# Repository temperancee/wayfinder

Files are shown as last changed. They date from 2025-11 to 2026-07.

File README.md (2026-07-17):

# Wayfinder

Wayfinder is a custom PCB I designed, containing an ICM-42670-P inertia measurement unit (IMU), a XIAO ESP32S3 Sense, and a barometer. The software is written in C using Arudino libraries and the Espressif-IDF version of FreeRTOS. The ESP32 communicates via I2C with the IMU via a custom driver I wrote. The accelerometer and gyroscope readings are then passed to a Kalman filter, which fuses the sensor data into roll and pitch angles, so you know the orientation of the board!

## Details

The Kalman filter is split into a predict task and a measurement task. The predict task reads gyroscope data, and incorporates it into the angle values using Euler integration. The measurement task reads accelerometer data, maps it to angles, and then incorporates it in the measurement step of the Kalman filter

The predict task runs every two milliseconds, and the measurement task runs every ten. There isn't really any reason for this in this project, although, for higher-end IMUs, accelerometer data is often generated slower than gyroscope data, so such a timing setup would be sensible.

Despite being called `icm_42670_p.cpp`, the code is all C. Arduino requires that external (non `.ino`) files are `.cpp`, rather than `.c`.

The IMU driver is exceedingly simple, and makes no use of the IMU's FIFO buffer. It simply provides commands for reading from the registers that store the gyroscope and accelerometer readings.

<!-- Originally intended to be a quadcopter flight computer, Wayfinder settled for the modest life of being an IMU board. Built using a custom PCB with a XIAO ESP32S3 Sense daughter board, and an ICM-42670-P IMU, this board outputs -->

## Running

If you want to use the driver, simply copy `icm_42670_p.h` and `icm_42670_p.cpp` into your Arduino project. 

## Licesnse

No licesnse. Do as you will with the code.

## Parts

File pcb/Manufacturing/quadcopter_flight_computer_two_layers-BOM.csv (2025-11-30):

Reference | Value | Footprint | Qty | Description | Distributor Link | Manufacturer | Manufacturer Part No. | Type
C1,C2 | 100n | Capacitor_SMD:C_0603_1608Metric | 2 | Unpolarized capacitor, small symbol | https://www.digikey.co.uk/en/products/detail/samsung-electro-mechanics/CL10B104KA8NNNC/3886664 | Samsung Electro-Mechanics | CL10B104KA8NNNC | SMD
C3 | 10n | Capacitor_SMD:C_0402_1005Metric | 1 | Unpolarized capacitor, small symbol | https://www.digikey.co.uk/en/products/detail/samsung-electro-mechanics/CL05B103KB5NNNC/3886686 | Samsung Electro-Mechanics | CL05B103KB5NNNC | SMD
C4 | 100n | Capacitor_SMD:C_0402_1005Metric | 1 | Unpolarized capacitor, small symbol | https://www.digikey.co.uk/en/products/detail/samsung-electro-mechanics/CL05B104KP5NNNC/3886660 | Samsung Electro-Mechanics | CL05B104KP5NNNC | SMD
C5 | 2u2 | Capacitor_SMD:C_0603_1608Metric | 1 | Unpolarized capacitor, small symbol | https://www.digikey.co.uk/en/products/detail/samsung-electro-mechanics/CL10B225KP8NNNC/3886792 | Samsung Electro-Mechanics | CL10B225KP8NNNC | SMD
D1,D2,D3,D4 | D_Small | My_Diode_SMD:D_SOD-123 | 4 | Diode, small symbol | https://www.digikey.co.uk/en/products/detail/diodes-incorporated/1N4148W-7-F/814371 | Diodes Incorporated | 1N4148W-7-F | SMD
D5 | D_TVS | My_Diode_SMD:D_SMA | 1 | Bidirectional transient-voltage-suppression diode, small symbol | https://www.digikey.co.uk/en/products/detail/bourns-inc/SMAJ5-0CA/2254237 | Bourns Inc. | SMAJ5.0CA | SMD
J2 | TO_XIAO | Connector_JST:JST_PH_B2B-PH-K_1x02_P2.00mm_Vertical | 1 | Generic connector, single row, 01x02, script generated (kicad-library-utils/schlib/autogen/connector/) | https://www.digikey.co.uk/en/products/detail/jst-sales-america-inc/B2B-PH-K-S/926611 | JST Sales America Inc. | B2B-PH-K-S | PTH
Q1,Q2,Q3,Q4 | NMOS | MOSFET:DMN1019USN | 4 | N-MOSFET transistor, drain/source/gate | https://www.digikey.co.uk/en/products/detail/diodes-incorporated/DMN1019USN-13/4898821 | Diodes Incorporated | DMN1019USN-13 | SMD
R1,R2,R3,R4 | 10k | Resistor_SMD:R_0603_1608Metric | 4 | Resistor, small symbol | https://www.digikey.co.uk/en/products/detail/samsung-electro-mechanics/RC1608F103CS/3903493 | Samsung Electro-Mechanics | RC1608F103CS | SMD
R5,R6 | 10k | Resistor_SMD:R_0402_1005Metric | 2 | Resistor, small symbol | https://www.digikey.co.uk/en/products/detail/samsung-electro-mechanics/RC1005F103CS/3903439 | Samsung Electro-Mechanics | RC1005F103CS | SMD
U1 | BMP390 | Barometer:BMP390 | 1 | BMP390 Digital pressure sensor | https://www.digikey.co.uk/en/products/detail/bosch-sensortec/BMP390/16164575 | Bosch Sensortec | BMP390 | SMD
U2 | ICM-42670-P | IMU:ICM-42670-P | 1 | ICM-42670-P 6-DOF | https://www.digikey.co.uk/en/products/detail/tdk-invensense/ICM-42670-P/14319524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 | TDK InvenSense | ICM-42670-P | SMD

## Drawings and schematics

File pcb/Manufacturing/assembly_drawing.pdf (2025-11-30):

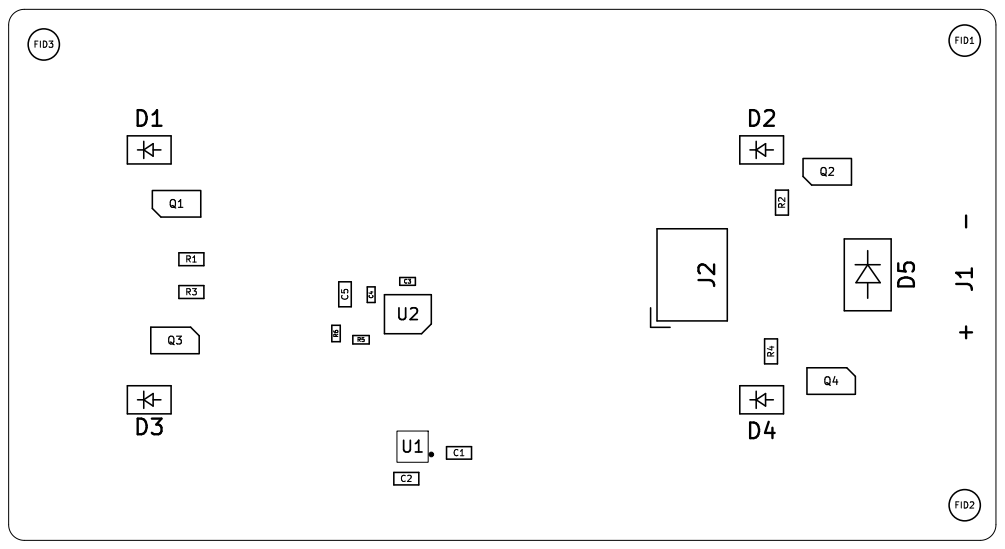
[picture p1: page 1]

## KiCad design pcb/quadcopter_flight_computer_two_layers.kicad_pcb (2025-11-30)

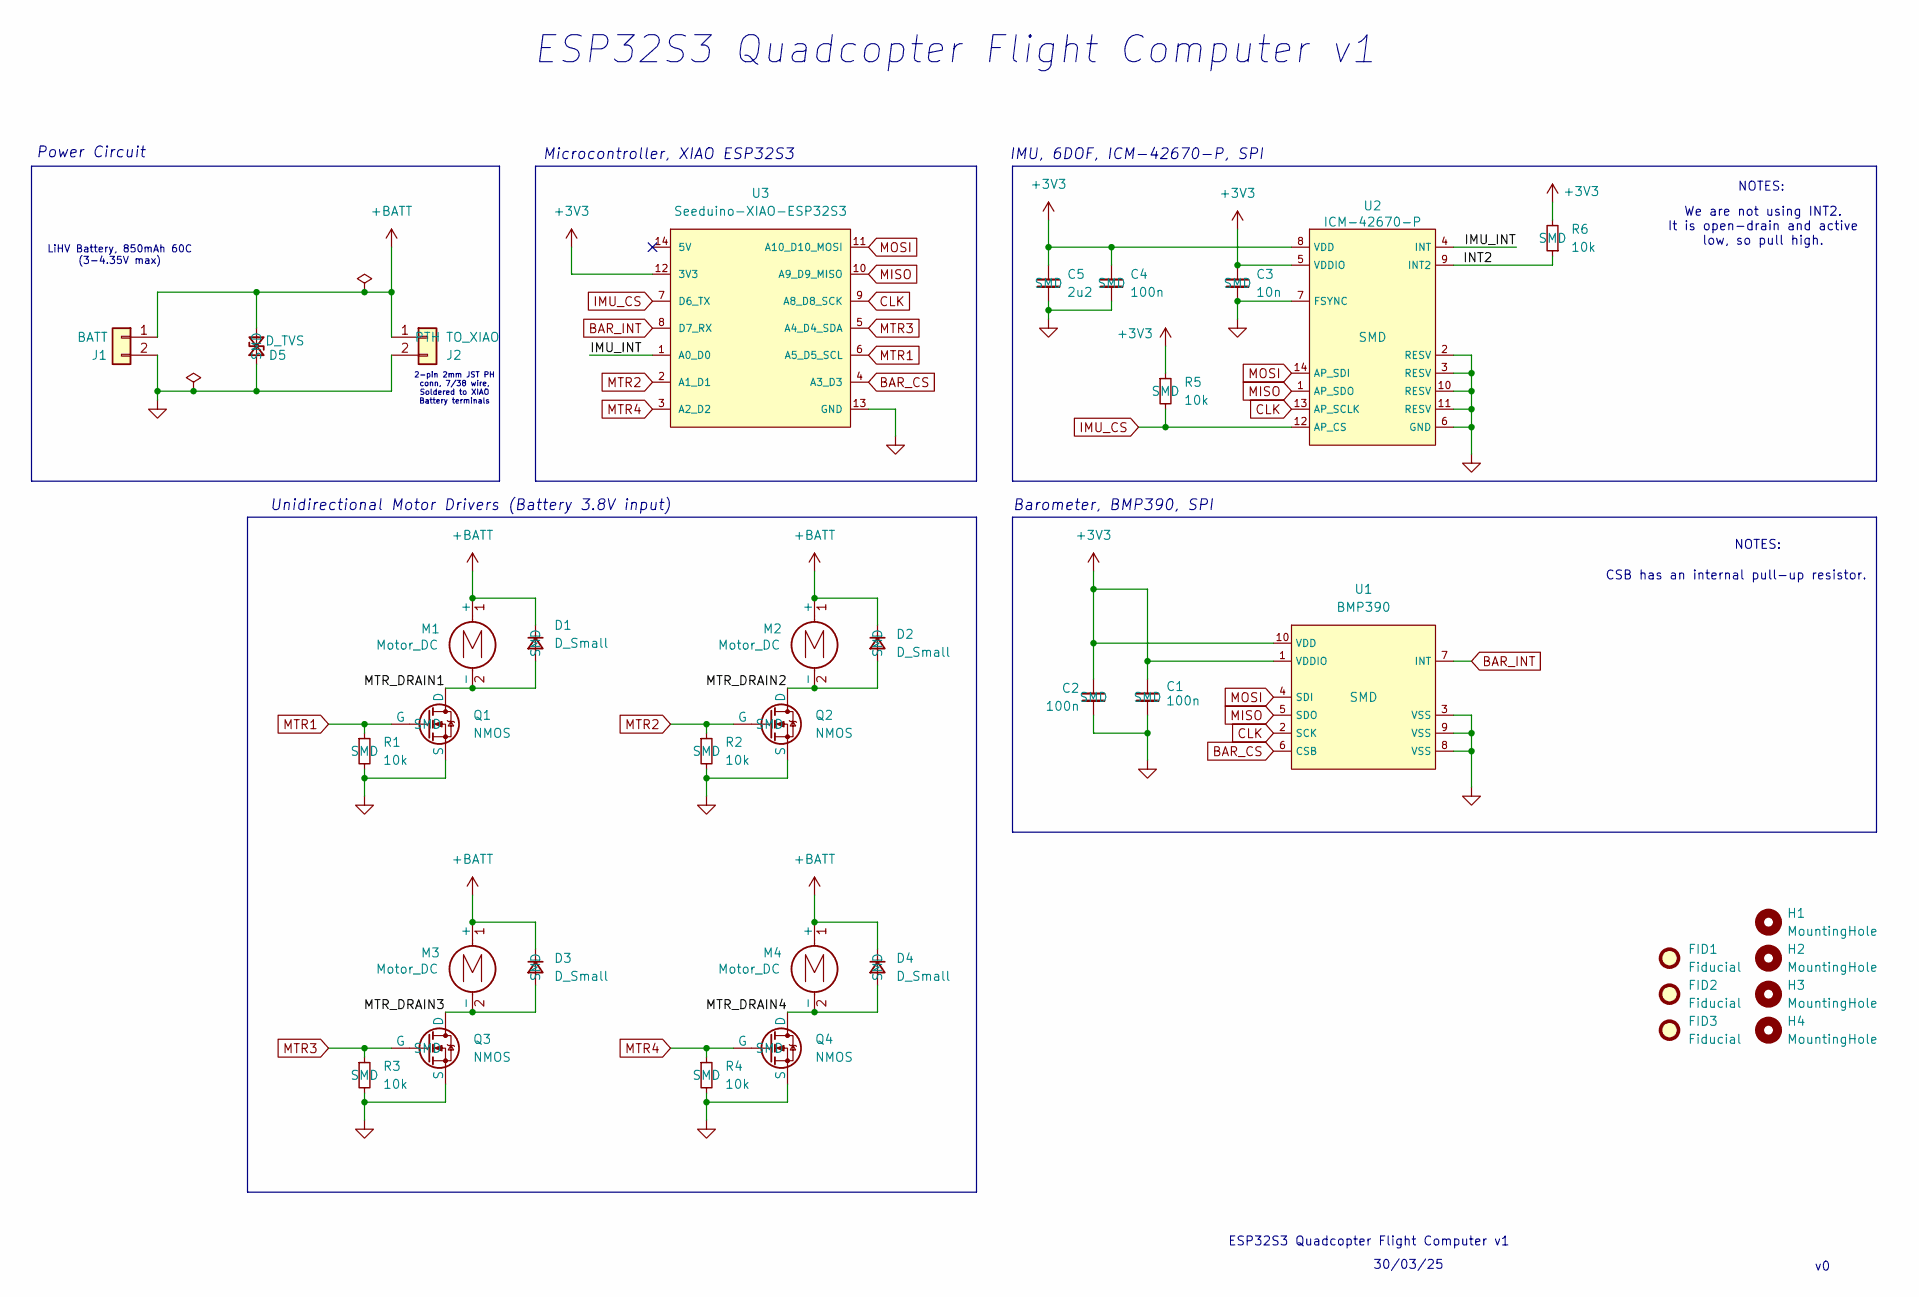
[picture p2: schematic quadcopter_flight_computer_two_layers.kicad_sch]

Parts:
C1, C2: 100n; C_0603_1608Metric; Manufacturer Part No. CL10B104KA8NNNC
C3: 10n; C_0402_1005Metric; Manufacturer Part No. CL05B103KB5NNNC
C4: 100n; C_0402_1005Metric; Manufacturer Part No. CL05B104KP5NNNC
C5: 2u2; C_0603_1608Metric; Manufacturer Part No. CL10B225KP8NNNC
D1, D2, D3, D4: D_Small; D_SOD-123; Manufacturer Part No. 1N4148W-7-F
D5: D_TVS; D_SMA; Manufacturer Part No. SMAJ5.0CA
FID1, FID2, FID3: Fiducial; Fiducial_1mm_Mask2mm
H1, H2, H3, H4: MountingHole; MountingHole_2.2mm_M2_DIN965
J1: BATT; 1S LiPo Battery
J2: TO_XIAO; JST_PH_B2B-PH-K_1x02_P2.00mm_Vertical; Manufacturer Part No. B2B-PH-K-S
M1, M2, M3, M4: Motor_DC; 8520_Coreless_Motor
Q1, Q2, Q3, Q4: NMOS; DMN1019USN; Manufacturer Part No. DMN1019USN-13
R1, R2, R3, R4: 10k; R_0603_1608Metric; Manufacturer Part No. RC1608F103CS
R5, R6: 10k; R_0402_1005Metric; Manufacturer Part No. RC1005F103CS
U1: BMP390; Manufacturer Part No. BMP390
U2: ICM-42670-P; Manufacturer Part No. ICM-42670-P
U3: Seeduino-XIAO-ESP32S3; XIAO-ESP32S3-THT

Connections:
+3V3: C1.1, C2.1, C3.1, C4.1, C5.1, R5.1, R6.2, U1.1 (VDDIO), U1.10 (VDD), U2.5 (VDDIO), U2.8 (VDD), U3.12 (3V3)
+BATT: D1.1 (K), D2.1 (K), D3.1 (K), D4.1 (K), D5.2 (A2), J1.1, J2.1, M1.1 (+), M2.1 (+), M3.1 (+), M4.1 (+)
/IMU_INT: U2.4 (INT), U3.1 (A0_D0)
/INT2: R6.1, U2.9 (INT2)
/MTR_DRAIN1: D1.2 (A), M1.2 (-), Q1.1 (D)
/MTR_DRAIN2: D2.2 (A), M2.2 (-), Q2.1 (D)
/MTR_DRAIN3: D3.2 (A), M3.2 (-), Q3.1 (D)
/MTR_DRAIN4: D4.2 (A), M4.2 (-), Q4.1 (D)
BAR_CS: U1.6 (CSB), U3.4 (A3_D3)
BAR_INT: U1.7 (INT), U3.8 (D7_RX)
CLK: U1.2 (SCK), U2.13 (AP_SCLK), U3.9 (A8_D8_SCK)
GND: C1.2, C2.2, C3.2, C4.2, C5.2, D5.1 (A1), J1.2, J2.2, Q1.3 (S), Q2.3 (S), Q3.3 (S), Q4.3 (S), R1.2, R2.2, R3.2, R4.2, U1.3 (VSS), U1.8 (VSS), U1.9 (VSS), U2.2 (RESV), U2.3 (RESV), U2.6 (GND), U2.7 (FSYNC), U2.10 (RESV), U2.11 (RESV), U3.13 (GND)
IMU_CS: R5.2, U2.12 (AP_CS), U3.7 (D6_TX)
MISO: U1.5 (SDO), U2.1 (AP_SDO), U3.10 (A9_D9_MISO)
MOSI: U1.4 (SDI), U2.14 (AP_SDI), U3.11 (A10_D10_MOSI)
MTR1: Q1.2 (G), R1.1, U3.6 (A5_D5_SCL)
MTR2: Q2.2 (G), R2.1, U3.2 (A1_D1)
MTR3: Q3.2 (G), R3.1, U3.5 (A4_D4_SDA)
MTR4: Q4.2 (G), R4.1, U3.3 (A2_D2)

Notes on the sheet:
Microcontroller, XIAO ESP32S3
Unidirectional Motor Drivers (Battery 3.8V input)
IMU, 6DOF, ICM-42670-P, SPI
LiHV Battery, 850mAh 60C (3-4.35V max)
We are not using INT2. It is open-drain and active low, so pull high.
NOTES:
ESP32S3 Quadcopter Flight Computer v1
CSB has an internal pull-up resistor.
2-pin 2mm JST PH conn, 7/38 wire, Soldered to XIAO Battery terminals
Power Circuit
30/03/25
Barometer, BMP390, SPI

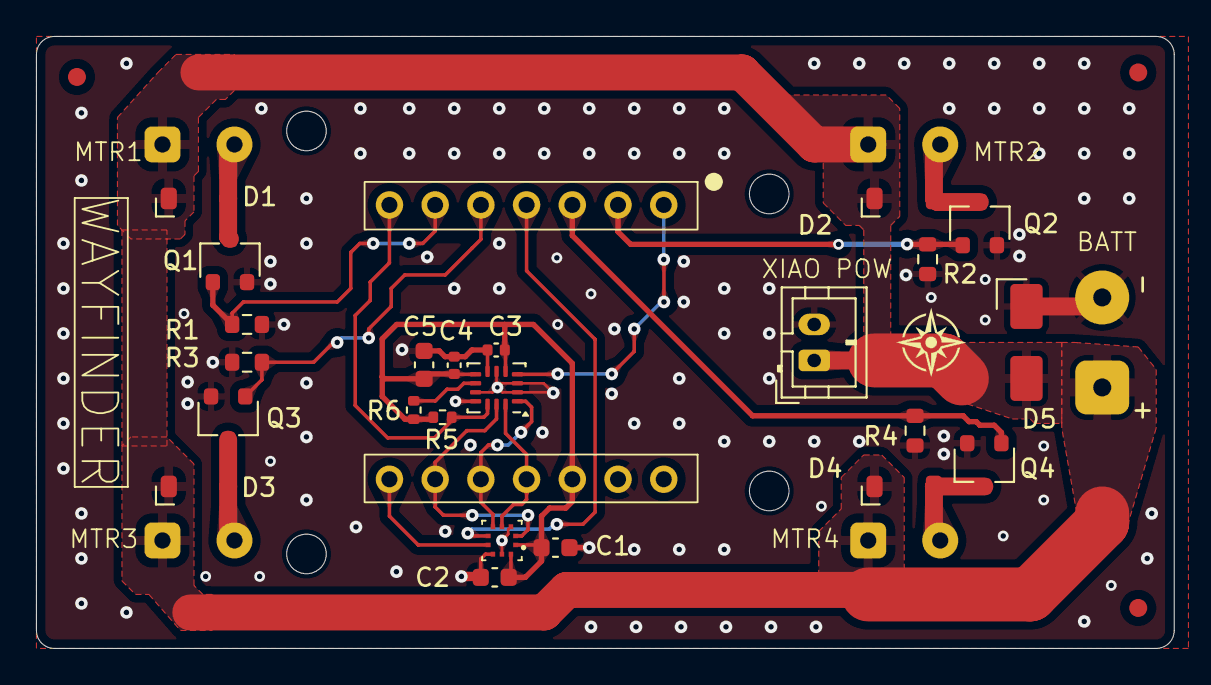
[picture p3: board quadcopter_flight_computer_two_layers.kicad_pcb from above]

Board: 2 copper layers, 63.2 x 34.0 mm, 36 parts (0 on the bottom side), 19 nets.

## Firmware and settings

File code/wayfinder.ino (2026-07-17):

// Use only core 1 because I don't know how to use multicores yet
#if CONFIG_FREERTOS_UNICORE
  static const BaseType_t app_cpu = 0;
#else
  static const BaseType_t app_cpu = 1;
#endif

#include "icm_42670_p.h"
#include <math.h>


/***************************
 * DEFINITIONS AND GLOBALS *
 ***************************/

/* Define pins */
const uint8_t INT_PIN = D0;
const uint8_t CS_PIN = D6;

/* Constants */

// Kalman Filter
#define t 2.0f              // Kalman filter predict time step in ms
#define MEASURE_TIME 10.0f      // Kalman filter measurement time step in ms
#define SIGMA_INIT 0.01f    // Initial values on diagonal of sigma (i.e. initial roll and pitch variances)
#define R_INIT 0.001f       // Initial values on diagonal of R (process noise)
#define Q_INIT 0.011f       // Initial values on diagonal of Q (measurement noise)

#define RAD_TO_DEG 57.2957795131f

/* Typedefs */
// Kalman Filter state and variance - initial state estimate is that roll and pitch are 0, as the drone will be lay flat.
typedef struct KalmanFilter {
    float roll;
    float pitch;
    float Sigma[4]; // Store as 4-dim array rather than 2x2 nested array for simplicity - 0 = 11, 1 = 12, 2 = 21, 3 = 22
    float R[2];     // R and Q are always diagonal matrices, so only store diagonal values - 0 = 11, 1 = 22
    float Q[2];
    SemaphoreHandle_t mutex;
} kalman;

/* Declare global objects */
icm_42670_p icm;
kalman kf;

// Task handles for timer callbacks
static TaskHandle_t predict_handle = NULL;
static TaskHandle_t measurement_handle = NULL;
static TimerHandle_t predict_timer = NULL;
static TimerHandle_t measurement_timer = NULL;

/***************************
 *        FUNCTIONS        *
 ***************************/

float sqr(float x)
{
    return x*x;
}

/***************************
 *        Callbacks        *
 ***************************/

void task_timer_callback(TimerHandle_t timer_handle)
{
    // This flag compares the priority of the task woken by the notification and the task
    // that was running before the ISR and runs the higher priority one accordingly
    BaseType_t higher_priority_task_woken = pdFALSE;

    // Check predict handle is not NULL - it shouldn't be, as we assign it in setup()
    configASSERT( predict_handle != NULL );

    // Send task notification to run predict/measurement step of Kalman Filter
    if (timer_handle == predict_timer) {
        vTaskNotifyGiveFromISR(predict_handle, &higher_priority_task_woken);
    } else {
        vTaskNotifyGiveFromISR(measurement_handle, &higher_priority_task_woken);
    } 

    // Run the higher priority task
    if (higher_priority_task_woken) {
        portYIELD_FROM_ISR();
    }
}

/***************************
 *          TASKS          *
 ***************************/


/* Kalman Filter prediction step */
void predict_task(void *arg)
{

    while (1) {

        // Run on timer interrupt - notification acts as binary semaphore
        if (ulTaskNotifyTake(pdTRUE, portMAX_DELAY) == 1) {

            // Read the data
            read_sensor_data(&icm);

            // Protect kf and icm objects with mutex
            if ( (xSemaphoreTake(kf.mutex, portMAX_DELAY) == pdTRUE) && (xSemaphoreTake(icm.mutex, portMAX_DELAY) == pdTRUE) ) {
                // Predict step
                kf.roll += (t/1000.0)*icm.gyro[0];
                kf.pitch += (t/1000.0)*icm.gyro[1];

                kf.Sigma[0] += kf.R[0];  
                kf.Sigma[3] += kf.R[1];

                xSemaphoreGive(kf.mutex);
                xSemaphoreGive(icm.mutex);
            }
            
        }
    
    }
}

/* Kalman Filter measurement step*/
void measurement_task(void *arg)
{
    // Roll and pitch angles as measured by the accelerometer
    float m_roll;
    float m_pitch;
    // Kalman gain
    float k_gain[4]; // Stored as a 1D array, just like Sigma
    float k_det;    // Determinant used in Kalman Gain calculation

    while (1) {

        // Run on timer interrupt - notification acts as binary semaphore
        if (ulTaskNotifyTake(pdTRUE, portMAX_DELAY) == 1) {

            // Read the data
            read_sensor_data(&icm);

            // Protect icm object with mutex
            if (xSemaphoreTake(icm.mutex, portMAX_DELAY) == pdTRUE) {
                // Initially, icm.accel values are 0. If this runs before the first data_ready interrupt comes in, m_roll and pitch will be NaN due to div by 0
                if (icm.accel[0] == 0) {
                    m_roll = 0;
                    m_pitch = 0;
                } else {
                    m_roll = atan( icm.accel[1] / sqrt( sqr(icm.accel[0]) + sqr(icm.accel[2]) ))*RAD_TO_DEG;
                    m_pitch = atan( -icm.accel[0] / sqrt( sqr(icm.accel[1]) + sqr(icm.accel[2]) ))*RAD_TO_DEG;
                }
                
                xSemaphoreGive(icm.mutex);
            }
            // Protect kf object with mutex
            if (xSemaphoreTake(kf.mutex, portMAX_DELAY) == pdTRUE) {

                // Kalman Gain
                k_det = 1 / ( (kf.Sigma[0]+kf.Q[0])*(kf.Sigma[3]+kf.Q[1]) - kf.Sigma[1]*kf.Sigma[2] );
                k_gain[0] = k_det * ( kf.Sigma[0]*(kf.Sigma[3] + kf.Q[1]) - kf.Sigma[1]*kf.Sigma[2] );
                k_gain[1] = k_det * ( kf.Sigma[1]*kf.Q[0] );
                k_gain[2] = k_det * ( kf.Sigma[2]*kf.Q[1] );
                k_gain[3] = k_det * ( kf.Sigma[3]*(kf.Sigma[0] + kf.Q[0]) - kf.Sigma[1]*kf.Sigma[2] );


                // State vector
                kf.roll += k_gain[0]*(m_roll - kf.roll) + k_gain[1]*(m_pitch - kf.pitch);
                kf.pitch += k_gain[2]*(m_roll - kf.roll) + k_gain[3]*(m_pitch - kf.pitch);

                // State variance
                kf.Sigma[0] = kf.Sigma[0]*(1 - k_gain[0]) + k_gain[1]*kf.Sigma[2];
                kf.Sigma[1] = kf.Sigma[1]*(1 - k_gain[0]) + k_gain[1]*kf.Sigma[3];
                kf.Sigma[2] = kf.Sigma[2]*(1 - k_gain[3]) + k_gain[2]*kf.Sigma[0];
                kf.Sigma[3] = kf.Sigma[3]*(1 - k_gain[3]) + k_gain[2]*kf.Sigma[1];

                xSemaphoreGive(kf.mutex);
            }

        }
        
    }
}

/* Prints to serial port */
void print_task(void *arg)
{

    uint8_t buf[1];

    while (1) {
        // Lock with mutex
        if (xSemaphoreTake(kf.mutex, portMAX_DELAY) == pdTRUE) { 
            Serial.print("Roll = ");
            Serial.print(kf.roll);
            Serial.print(" deg, ");
            Serial.print("Pitch = ");
            Serial.print(kf.pitch);
            Serial.println(" deg");
            Serial.println("---------------------------");

            xSemaphoreGive(kf.mutex);

            vTaskDelay(200 / portTICK_PERIOD_MS);
        }       
    }
}



/***************************
 *          SETUP          *
 ***************************/

void setup() 
{
    Serial.begin(115200);
    // Provide time for Serial to start up
    vTaskDelay(1000 / portTICK_PERIOD_MS);
    Serial.println();
    Serial.println("--- Begin ---");

    // Initialise ICM
    if (icm_initialise(&icm, CS_PIN) == -1) {
        Serial.println("ICM initialisation failed!!");
    }
      
    // Initialise KF 
    kf.mutex = xSemaphoreCreateMutex();
    kf.Sigma[0] = kf.Sigma[3] = SIGMA_INIT;
    kf.Sigma[1] = kf.Sigma[2] = 0;
    kf.R[0] = kf.R[1] = R_INIT;
    kf.Q[0] = kf.Q[1] = Q_INIT;

    // Create timer
    predict_timer = xTimerCreate("Predict Timer", t / portTICK_PERIOD_MS, pdTRUE, (void *)0, task_timer_callback);
    measurement_timer = xTimerCreate("Measurement Timer", MEASURE_TIME / portTICK_PERIOD_MS, pdTRUE, (void *)1, task_timer_callback);

    // Start tasks
    xTaskCreatePinnedToCore(predict_task, "predict_task", 2048, NULL, 2, &predict_handle, app_cpu);
    xTaskCreatePinnedToCore(measurement_task, "measurement_task", 2048, NULL, 2, &measurement_handle, app_cpu);
    xTaskCreatePinnedToCore(print_task, "print_task", 2048, NULL, 1, NULL, app_cpu);

    // Start timer
    configASSERT(predict_timer != NULL);
    xTimerStart(predict_timer, portMAX_DELAY);
    configASSERT(measurement_timer != NULL);
    xTimerStart(measurement_timer, portMAX_DELAY);

    // Delete setup and loop tasks
    vTaskDelete(NULL);
}

void loop() 
{
    // Execution should never reach here
}

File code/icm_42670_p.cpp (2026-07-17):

#include "esp32-hal-gpio.h"
#include "icm_42670_p.h"
#include "Arduino.h"
#include "HardwareSerial.h"
#include "freertos/idf_additions.h"
#include <cstdint>
#include <sys/types.h>


const SPISettings spi_settings(24000000, MSBFIRST, SPI_MODE0);


/***********************************************************************************************************************************************/
/* Functions */

uint8_t reg_write(icm_42670_p *icm, uint8_t reg_addr, uint8_t len, const uint8_t *buf)
{
    SPI.beginTransaction(spi_settings);
    digitalWrite(icm->CS_PIN, LOW); // Pull CS low to begin transaction
    // The device expects a R/W bit, then a 7 bit addr. We pass the function a 7 bit addr
    // and W=0, so by default this is already configured properly!
    SPI.transfer(reg_addr);
    for (int i=0; i<len; i++) {
        SPI.transfer(buf[i]);
    }
    digitalWrite(icm->CS_PIN, HIGH); // write CS high to end transaction
    SPI.endTransaction();
    return 0;
}


uint8_t reg_read(icm_42670_p *icm, uint8_t reg_addr, uint8_t len, uint8_t *buf)
{
    SPI.beginTransaction(spi_settings);
    digitalWrite(icm->CS_PIN, LOW); // Pull CS low to begin transaction
    // The device expects a R/W bit, then a 7 bit addr. We pass the function a 7 bit addr
    // then edit the MSB bit to be R=1
    SPI.transfer(reg_addr | (1 << 7));
    for (int i=0; i<len; i++) {
        buf[i] = SPI.transfer(0x00); // send a value of 0 to read the byte returned
    }
    digitalWrite(icm->CS_PIN, HIGH); // write CS high to end transaction
    SPI.endTransaction();
    return 0;
}

uint8_t icm_initialise(icm_42670_p *icm, const uint8_t CS_PIN)
{
    // Attach pins to ICM object
    icm->CS_PIN = CS_PIN;

    // Set up CS pins as outputs - Arduino does not handle CS pins automatically
    pinMode(CS_PIN, OUTPUT);
    SPI.begin();

    /* Initialise icm mutex */
    icm->mutex = xSemaphoreCreateMutex();

    reg_write(icm, PWR_MGMT0, 1, &VAL_PWR_MGMT0); // Turn on the accel and gyro
    vTaskDelay(300 / portTICK_PERIOD_MS); // The datasheet says not to write to any register for 200us after turning the gyro and accel on
    reg_write(icm, GYRO_CONFIG0, 1, &VAL_GYRO_CONFIG0); // Configure Gyro FS and ODR
    reg_write(icm, ACCEL_CONFIG0, 1, &VAL_ACCEL_CONFIG0); // Configure Accel FS and ODR

    /* Check if we can read whoami register. If not, return error */
    uint8_t who_am_i;
    reg_read(icm, WHO_AM_I, 1, &who_am_i);
    if (who_am_i != 0x67) {
        return -1;
    }

    return 0;
}

/***********************************************************************************************************************************************/
/* Tasks */

void read_sensor_data(icm_42670_p *icm)
{
    uint8_t data_buf[GYRO_ACCEL_REG_SIZE];
    uint8_t buf[1];

    reg_read(icm, ACCEL_DATA_X1, GYRO_ACCEL_REG_SIZE, data_buf);
    
    /* accelerometer data is 16 bit 2s complement, stored in 2 separate 8-bit registers */
    int16_t accel_raw[3];
    accel_raw[0] = ((int16_t)data_buf[0] << 8) | ((int16_t)data_buf[1]);
    accel_raw[1] = ((int16_t)data_buf[2] << 8) | ((int16_t)data_buf[3]);
    accel_raw[2] = ((int16_t)data_buf[4] << 8) | ((int16_t)data_buf[5]);

    /* gyro data is 16 bit 2s complement, stored in 2 separate 8-bit registers */
    int16_t gyro_raw[3];
    gyro_raw[0] = ((int16_t)data_buf[6] << 8) | ((int16_t)data_buf[7]);
    gyro_raw[1] = ((int16_t)data_buf[8] << 8) | ((int16_t)data_buf[9]);
    gyro_raw[2] = ((int16_t)data_buf[10] << 8) | ((int16_t)data_buf[11]);

    float accel_x = (accel_raw[0] / (float)ACCEL_SENS) * 9.81;
    float accel_y = (accel_raw[1] / (float)ACCEL_SENS) * 9.81;
    float accel_z = (accel_raw[2] / (float)ACCEL_SENS) * 9.81;

    float gyro_x = (float)gyro_raw[0] / GYRO_SENS; // - gyro_roll_offset;
    float gyro_y = (float)gyro_raw[1] / GYRO_SENS; // - gyro_pitch_offset;
    float gyro_z = (float)gyro_raw[2] / GYRO_SENS; // - gyro_yaw_offset;

    /* Critical section - use mutex to protect mpu6050 object */
    if (xSemaphoreTake(icm->mutex, portMAX_DELAY) == pdTRUE) {
        icm->accel[0] = accel_x;
        icm->accel[1] = accel_y;
        icm->accel[2] = accel_z;

        icm->gyro[0] = gyro_x;
        icm->gyro[1] = gyro_y;
        icm->gyro[2] = gyro_z;

        xSemaphoreGive(icm->mutex);
    }
    
}

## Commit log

2025-07-04 Kalman Filter (no interrupt ver.) working
2025-07-05 Added PID loops
2025-11-30 Added KiCAD PCB files
    [power_circuit.kicad_sch, quadcopter_flight_computer_two_layers-BOM.csv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]
